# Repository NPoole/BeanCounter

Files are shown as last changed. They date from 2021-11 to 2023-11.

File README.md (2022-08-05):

# BeanCounter

[][cc-by-sa]

BeanCounter is an SMT parts counter that fits in your pocket. It’s battery powered and uses two IR photointerrupters to count parts about as fast as you can pull them through. It works with any opaque, 8-mm-wide carrier tape up to 2 mm in height, which covers most 0805-or-smaller LEDs and passives, as well as SOT23 transistors. It’s an affordable SMT tape counter without unnecessary bells and whistles.

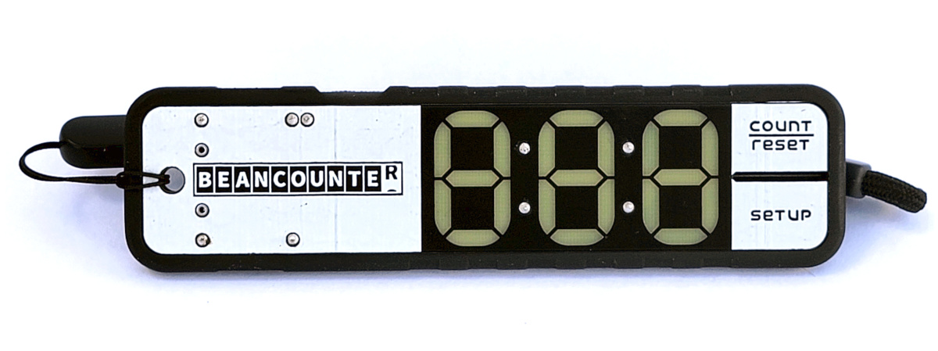
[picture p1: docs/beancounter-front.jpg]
BeanCounter on white background


## Available for Pre-Order Now on [Crowd Supply](https://www.crowdsupply.com/great-big-factory/beancounter)!

To use BeanCounter, simply turn it on and start pulling tape through. It will immediately begin counting your parts using one of two modes:

* Inventory Mode - Using just one sensor, BeanCounter polls at its fastest rate, allowing you to count long tapes and partial reels very quickly.
* Dispense Mode - With both sensors active, BeanCounter can detect the direction in which you are pulling tape, which allows it to count upward in one direction and downward in the other. This feature is useful in kitting contexts where you may be cutting fixed quantities off the end of a full reel.
Part pitch is configurable in either mode, so you can accurately count any part that physically fits through the counter.

Digging a little deeper, what BeanCounter actually does is count feed holes and divide by the part pitch. Because it cannot differentiate between parts and empty pockets, you will need to ensure that it begins counting after empty tape has been pulled through and stops counting before it reaches the tail. To help with this, we’ve added a "pause" button that you can use to freeze the count while pulling empty tape.

[cc-by-sa]: http://creativecommons.org/licenses/by-sa/4.0/
[cc-by-sa-shield]: https://img.shields.io/badge/License-CC%20BY--SA%204.0-lightgrey.svg

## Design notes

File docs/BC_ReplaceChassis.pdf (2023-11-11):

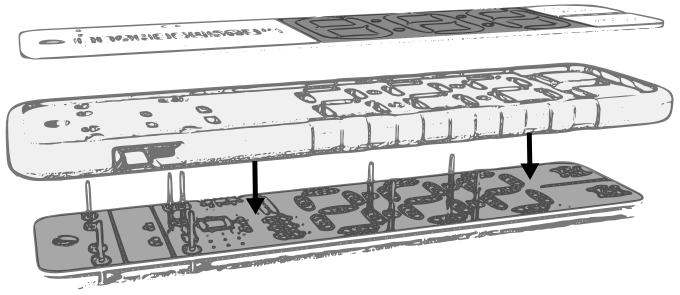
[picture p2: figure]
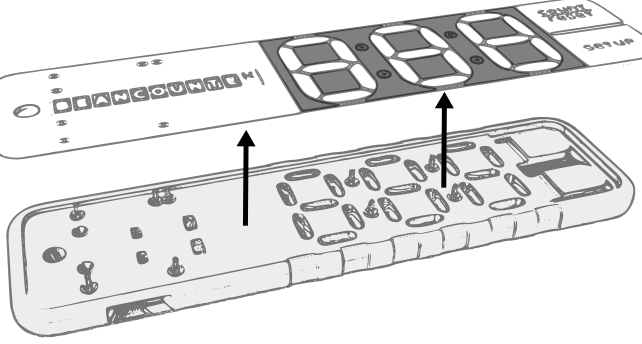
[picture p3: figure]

3609 Chapman Road
Wytheville, VA 24382 USA
support@greatbigfactory.com http://beancounter.wiki
OSHW UID US002097

CONTACT US

# How to Replace the Chassis

Step 1 - Desolder the Chassis Pins

Use a desoldering tool or copper wick to remove all solder from the 9 points indicated by the arrows below

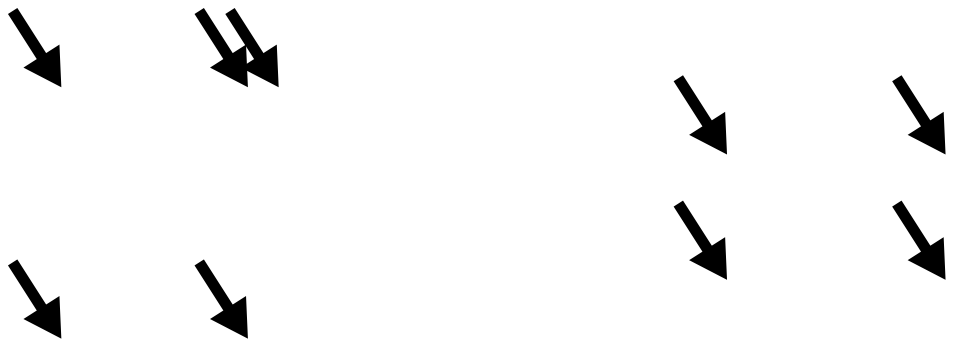
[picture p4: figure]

Step 2 - Remove the faceplate

Carefully pull the faceplate free from the rest of the assembly. If necessary, you can gently flex the chassis to reach a flat tool under the edge of the faceplate

Step 3 - Separate the backplate from the chassis
Step 4 - Re-Assemble the BeanCounter in the reverse order with your new chassis

The backplate should easily separate from the chassis. If necessary, you can press on the pins from the front to dislodge it.

Be sure that the face- and backplates are firmly seated into the chassis while soldering the 9 chassis pins. Using a small spring clamp can help, but it's sufficient to apply presure with your fingers.

.step | .stl

DOWNLOAD V11 CHASSIS MODELS

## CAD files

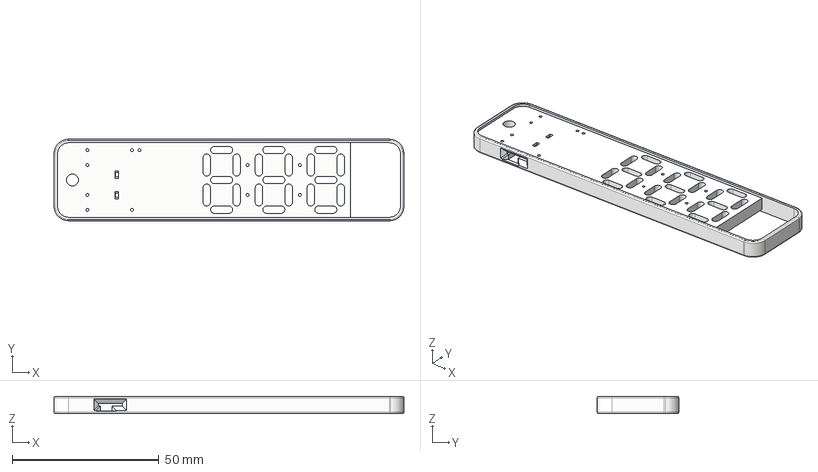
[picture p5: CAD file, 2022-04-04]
hardware/cad/BC_3DP_Simple_Resin v1.step
119.2 x 27.8 x 5.90 mm

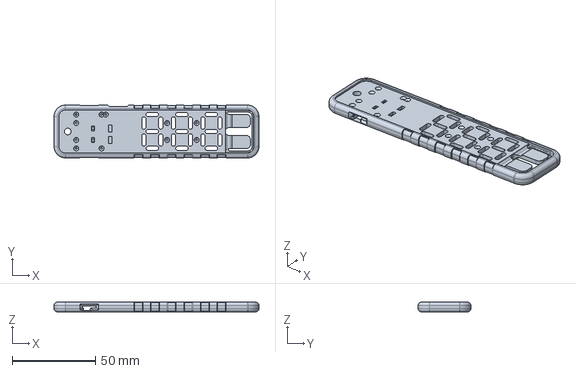
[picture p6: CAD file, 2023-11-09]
mechanical/BeanCounter_Rev11.step
123.2 x 31.8 x 5.90 mm

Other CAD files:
mechanical/BeanCounter_v10_Stock.step
mechanical/BeanCounter_Tall_Slot_Mod.stl
hardware/cad/BC_3DP_Simple_Resin v1.3mf
hardware/cad/BC_3DP_Simple_Resin v1.f3d
hardware/cad/BC_3DP_Simple_Resin v1.iges
mechanical/BeanCounter_Rev11.stl
mechanical/BeanCounter_v10_Stock.f3d
mechanical/BeanCounter_v10_Stock.stl

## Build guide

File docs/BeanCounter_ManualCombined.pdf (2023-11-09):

### SMT TAPE COUNTER V10 USER MANUAL

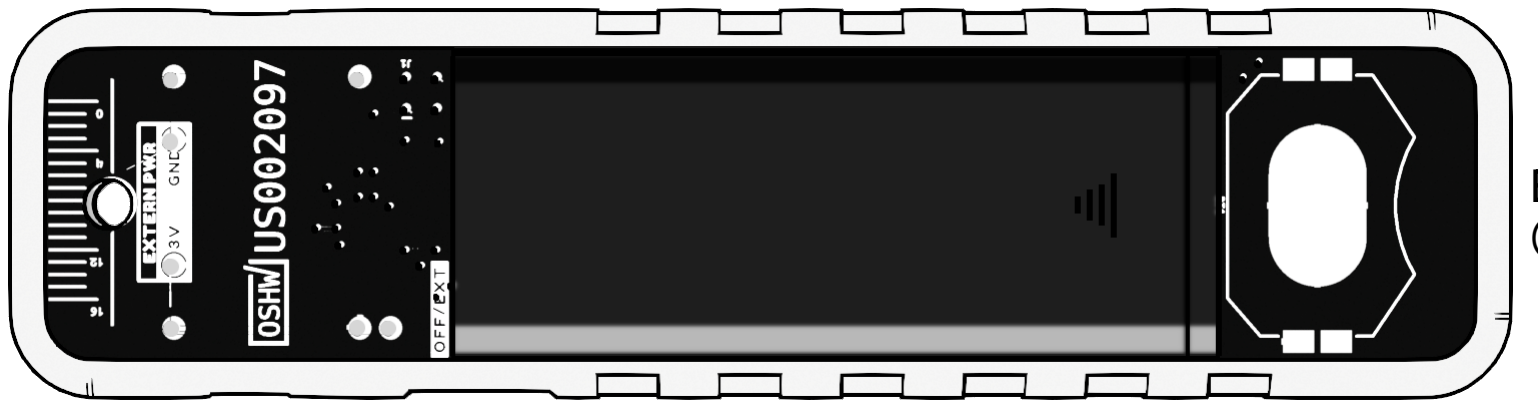
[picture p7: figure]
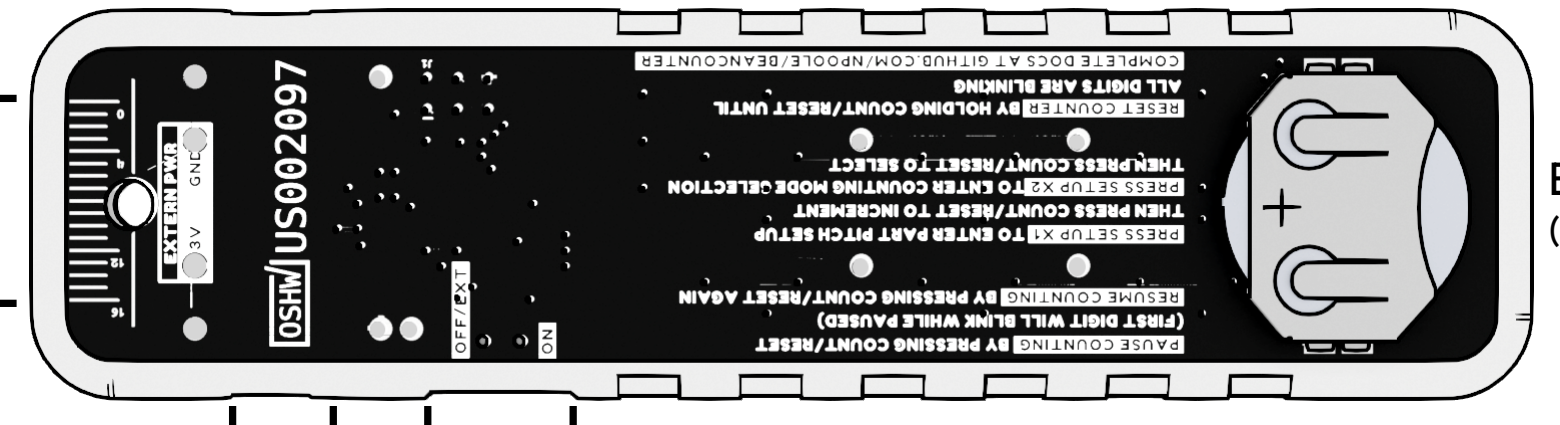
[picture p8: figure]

Display | Buttons

Tape
Slot

Power
Switch

Lanyard
Hole

BOTTOM VIEW
(BEANCOUNTER-10-BUBU)

-The batteries included with your BeanCounter are not rechargeable. These batteries could explode if you attempt to charge them. Do not attempt to charge disposable batteries.

Unit Size: 124x32x11mm (BEANCOUNTER-10) 124x32x24mm (BEANCOUNTER-10-BUBU) Unit Weight: ≈30g (BEANCOUNTER-10)
≈60g (BEANCOUNTER-10-BUBU) Batteries: "CR2032" Lithium Coin Cell or "LIR2032" Li-ion Rechargeable (BEANCOUNTER-10) 2 x "AAA" Alkaline or NiMH Rechargeable (BEANCOUNTER-10-BUBU)
Supported Tape Pitch in mm: 1, 2, 4, 8, 12, 16 Supported Tape Type: 8mm wide carrier tape, embossed plastic or paper type, <2mm part height.

-Before feeding carrier tape into the unit, cut off any empty portion of the tape. If this is impossible or undesirable, you must feed the empty portion through the unit before starting the count.
- In order to receive an accurate count, the part pitch must be set correctly. To do this, first press the SETUP button and observe that the display reads P followed by a number. This number is the pitch in millimeters. Press the COUNT/RESET button to increment this number. When the desired pitch is displayed, press SETUP twice to return to counting mode.

-If the display does not read 000 then it can be cleared by holding the COUNT/RESET button until the display begins to flash, and then releasing it.
-If the first digit of the display is flashing then the unit is paused. To begin counting, press the COUNT/RESET button. You can press the COUNT/RESET button at any time to turn off the sensors and pause counting without clearing the display.
-Carrier tape can be inserted into either end of the tape slot. However, the sprocket holes must be facing to the right (as viewed so that the BeanCounter logo is upright.)
-Pull or push the tape through the tape slot and observe that the parts count is increasing on the display. To ensure an accurate count, move the tape in a fluid motion and avoid jiggling or quickly switching the direction of motion.
-If the tape does not glide freely in the tape slot do not force it.
-In order to reset the count and clear the display, hold the COUNT/RESET button until the display begins to flash, and then release it.
-To ensure maximum battery life, turn the BeanCounter off when not in use.

BeanCounter has two counting modes: Inventory Mode and Dispense Mode. In Inventory Mode, the unit will use only one of its sensors to count as quickly as possible. This has the consequence that counts in both directions will be added together because the unit is unaware of the direction of count. This mode makes the BeanCounter capable of counting twice as fast, which is useful for counting long tape and partial reels. In Dispense Mode, the unit will use both of its sensors to count in both directions. This is handy for situations where you need to dispense a small number of parts such as when kitting or packing.

To switch modes, press the SETUP button twice and observe that the display reads either d15 for Dispense Mode or1nu for Inventory Mode. Press the COUNT/RESET button to toggle modes. When the desired mode is displayed, press the SETUP button to return to counting mode.

3609 Chapman Road
Wytheville, VA 24382 USA
support@greatbigfactory.com http://beancounter.wiki
OSHW UID US002097

-Do not place your BeanCounter on or allow it to rest on an electrically conductive surface.

Read and understand this manual and all safety instructions before operating this equipment.

The BeanCounter product is provided "AS IS." Great Big Factory makes no warranty, representation, or guarantee as to the fitness of this device for any specific purpose, nor does Great Big Factory assume any liability whatsoever arising from the function or malfunction of the BeanCounter device (to the extent permissible by law.) Great Big Factory assumes no obligation to replace or repair a BeanCounter device for any reason.

Due to physical limitations of the sensor, BeanCounter is not compatible with transparent carrier tapes.

-Do not place anything into the tape slot other than embossed plastic or paper carrier tape.

-Do not submerge or otherwise expose your BeanCounter to water.

BOTTOM VIEW
(BEANCOUNTER-10)

TOP VIEW
(ALL MODELS)

Pitch
Ruler
SAFETY INFORMATION | GENERAL OPERATION Preparation

## Counting

## Selecting a Counting Mode

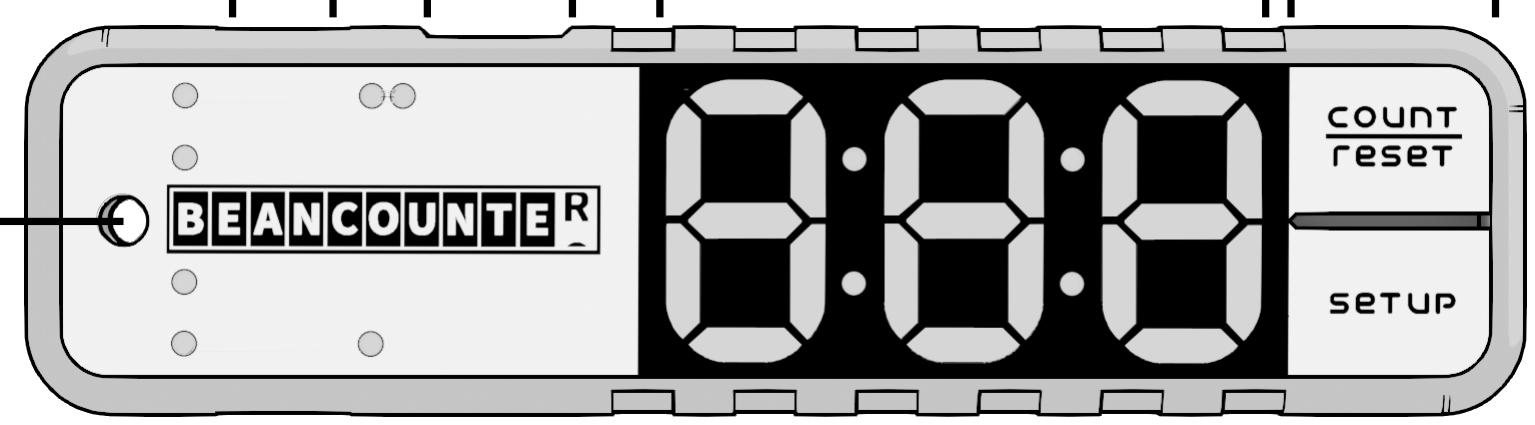
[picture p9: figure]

## Find tips, troubleshooting, and detailed operating instructions at: http://beancounter.wiki

# SPECIFICATIONS

WARRANTY DISCLAIMER | CONTACT US

# EQUIPMENT DIAGRAM

Manufactured in Partnership With | Made Possible By
&

!

### SMT BANDZÄHLER

V10 BEDIENUNGSANLEITUNG

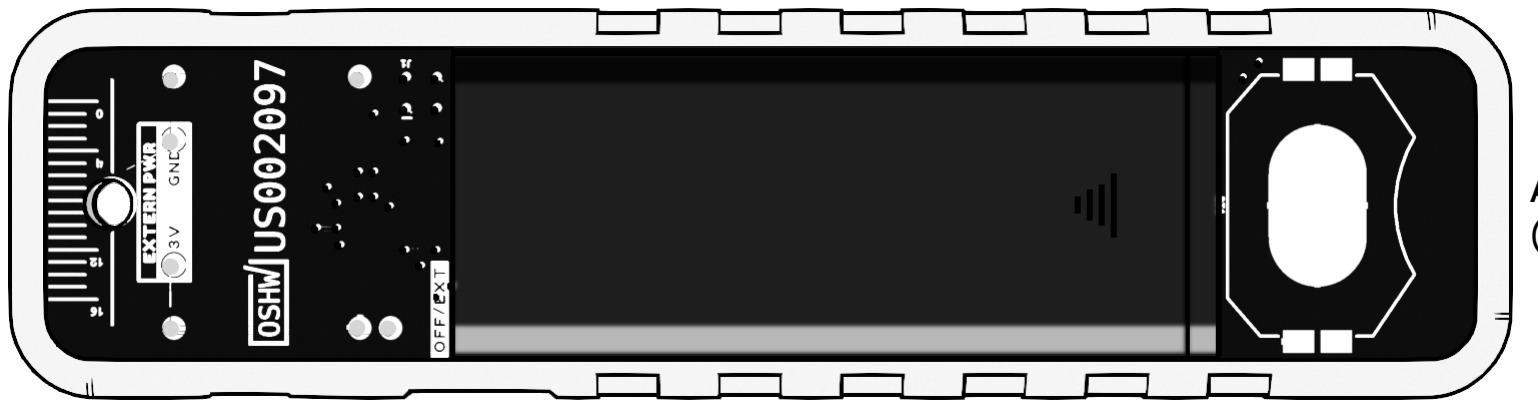
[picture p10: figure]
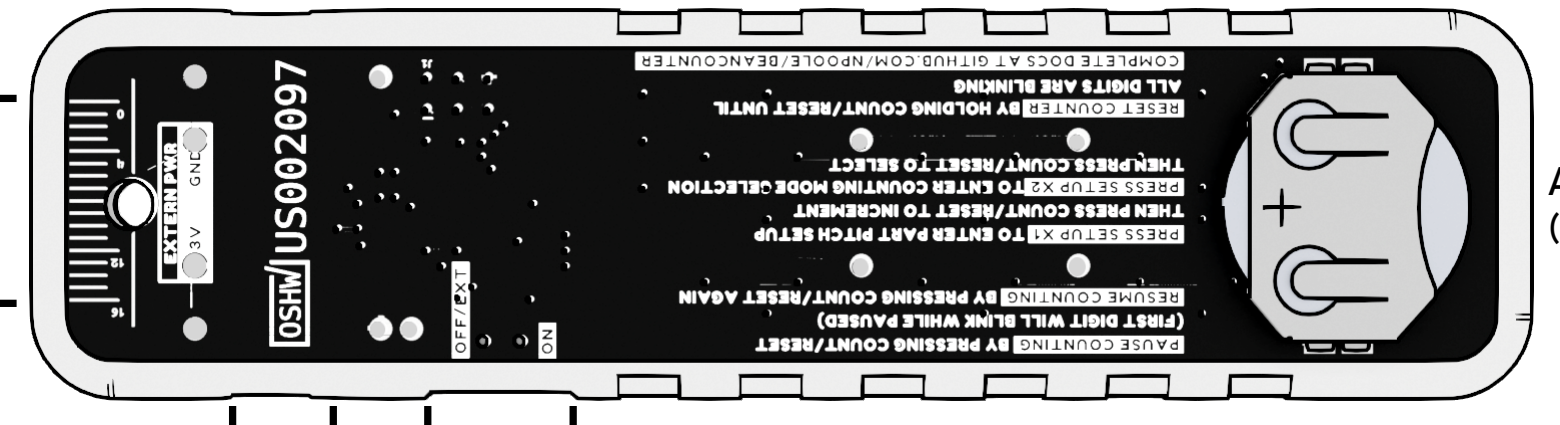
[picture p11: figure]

Anzeige | Tasten Gurtschlitz | Ein-/Ausschalter

Lanyard-Loch

ANSICHT VON UNTEN
(BEANCOUNTER-10-BUBU)

-Die Ihrem BeanCounter beiliegenden Batterien
sind nicht wiederaufladbar. Beim Versuch, sie aufzuladen, können diese Batterien explodieren. Bitte versuchen Sie nicht, Einwegbatterien aufzuladen.

Abmessungen: 124x32x11mm (BEANCOUNTER-10) 124x32x24mm (BEANCOUNTER-10-BUBU) Gewicht: ≈30g (BEANCOUNTER-10)
≈60g (BEANCOUNTER-10-BUBU) Batterien: "CR2032" Lithium-Knopfzelle oder "LIR2032" Li-Ionen-Akku (BEANCOUNTER-10)
2 x "AAA" Alkaline oder NiMH wiederaufladbar (BEANCOUNTER-10-BUBU)
Verwendbare Gurtabstand in mm: 1, 2, 4, 8, 12, 16 Verwendbare Gurttypen: 8mm gurtbreiten ,
Gurten aus Karton oder Kunststoff, <2mm Profilhöhe.

-Bitte schneiden Sie vor dem Einführen des Gurte in das Gerät den leeren Teil des Gurte
ab. Falls dies nicht möglich oder unerwünscht ist, führen Sie den leeren Teil durch das Gerät, bevor Sie mit der Zählung beginnen.
- Um eine exakte Zählung zu erhalten, muss der Teilungsabstand korrekt eingestellt sein. Dazu drücken Sie zunächst die SETUP-Taste und beobachten, dass auf dem Display P gefolgt von einer Zahl erscheint. Bei dieser Zahl handelt es sich um die Teilung in Millimetern. Betätigen Sie die COUNT/RESET-Taste, um diese Zahl zu erhöhen. Sobald die gewünschte Tonhöhe angezeigt wird, drücken Sie zweimal SETUP, um in den Zählmodus zurückzukehren.

-Falls die Anzeige nicht 000 anzeigt, kann sie gelöscht werden, indem Sie die Taste COUNT/RESET gedrückt halten, bis die Anzeige zu blinken beginnt, und sie dann loslassen.
-Blinkt die erste Ziffer auf der Anzeige, ist das Gerät pausiert. Um den Zählvorgang zu starten, drücken Sie die COUNT/RESET-Taste. Um die Sensoren auszuschalten und die Zählung zu unterbrechen, ohne die Anzeige zu löschen, können Sie jederzeit die COUNT/RESET-Taste drücken. -Das Trägerband lässt sich in beide Enden des Gurtschlitzes einführen. Jedoch müssen die Stachelradlöcher nach rechts gerichtet sein (so gesehen, dass das BeanCounter-Logo
aufrecht steht).
-Das Gurt durch den Gurtschlitz ziehen oder schieben und darauf achten, dass die Anzahl der Teile auf dem Display Anzeige steigt. Bewegen Sie das Gurt in einer fließenden Bewegung und vermeiden Sie ein Wackeln oder einen schnellen Wechsel der Bewegungsrichtung, um eine genaue Zählung zu gewährleisten.
-Gleitet das Gurt nicht ungehindert in den Gurtschlitz, sollten Sie es nicht mit Gewalt bewegen. -Zum Zurücksetzen der Zählung und Löschen der Anzeige halten Sie die COUNT/RESET-Taste gedrückt, bis die Anzeige zu blinken beginnt, und lassen Sie sie dann los.
-Um die Lebensdauer der Batterie zu verlängern, schalten Sie den BeanCounter aus, wenn er nicht benutzt wird.

BeanCounter verfügt über zwei Zählmodi: Inventar-Modus und Dispense-Modus. Im Inventar-Modus wird das Gerät nur einen seiner Sensoren verwenden, um so schnell wie möglich zu zählen. Dadurch werden die Zählungen in beide Richtungen addiert, da dem Gerät die Zählrichtung nicht bekannt ist. Der BeanCounter ist in diesem Modus in der Lage, doppelt so schnell zu zählen, was beim Zählen von langen Gurten und Rolle nützlich ist. Im Dispense-Modus nutzt das Gerät
beide Sensoren, um in beide Richtungen zu zählen. Diese Funktion ist praktisch für Situationen, in denen Sie eine kleine Anzahl von Teilen ausgeben müssen, wie z.B. beim Kitting oder Verpacken.

Um die Modi zu wechseln, betätigen Sie zweimal die SETUP-Taste und achten Sie darauf, dass auf der Anzeige entweder d15 für den Dispense-Modus oder1nu für den Inventar-Modus erscheint. Zum Umschalten der Modi drücken Sie die Taste COUNT/RESET. Sobald der gewünschte Modus angezeigt wird, drücken Sie die SETUP-Taste, um zum Zählmodus zurückzukehren.

3609 Chapman Road
Wytheville, VA 24382 USA
support@greatbigfactory.com http://beancounter.wiki
OSHW UID US002097

-Den BeanCounter nicht auf eine elektrisch leitfähige Oberfläche stellen oder liegen lassen.

Bitte lesen und befolgen Sie dieses Bedienungsanleitung und alle Sicherheitshinweise, bevor Sie das Gerät in Betrieb nehmen.

Dieses Produkt wird ohne Mängelgewähr bereitgestellt.
Great Big Factory übernimmt keine Garantie, Zusicherung oder Gewährleistung für die Eignung dieses Geräts für einen bestimmten Zweck, noch übernimmt Great Big Factory irgendeine Haftung, die sich aus der Funktion oder Fehlfunktion des BeanCounter-Geräts ergibt (soweit gesetzlich zulässig). Great Big Factory ist nicht verpflichtet, ein BeanCounter Gerät aus irgendeinem Grund zu ersetzen oder zu reparieren.

Infolge der physikalischen Limitierungen des Sensors ist der BeanCounter nicht mit transparenten Gurte kompatibel.

-Keine anderen Gegenstände als Gurte in den Gurtschlitz stecken.

-Bitte niemals den BeanCounter unter Wasser tauchen oder anderweitig mit Wasser in Berührung bringen.

ANSICHT VON UNTEN
(BEANCOUNTER-10)

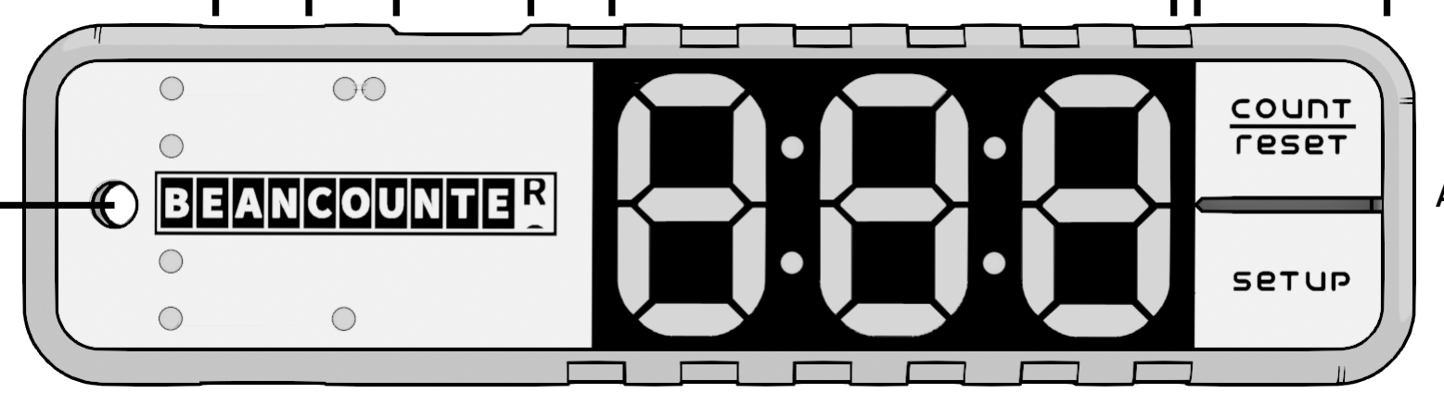
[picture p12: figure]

ANSICHT VON OBEN

Lineal

SICHERHEITSHINWEISE | ALLGEMEINE BEDIENUNG Vorbereitung

## Zählen

## Zählmodus auswählen

Hinweise, Problemlösungen und detaillierte Bedienungsanleitungen finden Sie unter:

## http://beancounter.wiki

# TECHNISCHE ANGABEN

HAFTUNGSAUSSCHLUSS | KONTAKT

# GERÄTEÜBERSICHT

Hergestellt in Partnerschaft mit | Ermöglicht durch
&

!

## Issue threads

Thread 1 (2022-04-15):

Bill of materials

foorschtbar, 2022-04-15:
Very cool gadget you have developed. I liked it since i saw it on twitter.

Will you upload a BOM so that everybody can build the BeanCounter yourself - or did I just overlook that?

e-tinkers, 2022-04-18:
Well, for those who know electronics and embedded programming, one could create a device like this and write his own code even without seeing the schematic.

For those who can't even generate the BOM (or who is capable but unwilling to invest time on it) when giving the component footprints, PCB layout and schematic, maybe one should just buy one from the @Npoole and support his [CrownSupply](https://www.crowdsupply.com/great-big-factory/beancounter) project.

foorschtbar, 2022-04-21:
I have not seen that the Eagle files are there. Now everything is clear.

Closed 2022-04-21.

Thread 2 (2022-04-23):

Design enhancements

j3qq4hch, 2022-04-23:
Greetings! I really like your idea and the implementation in a form if mostly PCBs.
I hope your crowdsupply campaign will be succesfull.
However I see at least several improvements to this project that may be very useful for high scale manufacturability, BOM cost and components lead time reduction. As well as for higher device reliability. Please let me know if you are interested. If not - just delete this issue.
Best regards.

NPoole, 2022-04-29:
I think we're locked in for the campaign hardware, but I'm happy to hear any feedback you have for future revisions or "Pro" model offerings.

j3qq4hch, 2022-04-29:
Well, I will just leave a small list of enhancements here
- Switch to a cheaper and more available MCU like something from STM32G0 series
- Get rid of the 3d printed part and replace it with either another PCB or laser cut plastic part.
- The way everything holds together using soldered pins is a bit untidy...  It is always better if no circuitry is exposed. Also, its good to have a device that can actually be disassembled with a screwdriver
- It seems like something has to be done with the indicator. I think its readability can be improved a bit.
- I am not sure but it seems that mechanical buttons may be replaced with sensor ones. It may reduce the BOM cost a little bit and also ease the overall construction.

NPoole, 2022-05-16:
Thanks for your time! I'm going to leave this issue open for the time being while I collect feedback and compile it.

je2442, 2023-08-31:
I would add a few things to the list:

- It would be really nice if it could be enhanced to handle slightly taller and possibly wider components (1206 and SOD-123, for a couple of examples).
- I find that the count is sometimes off by 2 or 4...not sure why.  That's not a huge issue for me, but I wonder if that could be improved.  Maybe it depends on where the tape is cut exactly in relation to the holes.
- I also think the LED display readability should be improved a bit.  Some of our office lighting makes it unreadable.
- Future enhancement to work with additional tape widths would be great.
- I might try to retrofit mine with a rechargeable battery.  That would be a good option for future consideration.

It is pretty nice for a budget-friendly counter, though!

Geo-7777, 2025-03-28:
For our application we would need a 4th digit our counts are usually close to 3000 to 4000 pcs otherwise your unit works really well for our needs, hope you consider this in your next revision

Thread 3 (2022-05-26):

Suggestion: wirless capability

matmair, 2022-05-26:
Hi there @NPoole !
Cool project. If you end up spinning up a rev 2 it would be cool to have some wireless function included if it fits in your overall plan for the product. This would be helpful to get the current count into an ERP/PLM.
Several interfaces would be beneficial:
- *Wifi* would require some primitive API that can be queried but could be very versetail
- *Bluetooth* provides a profile for scales that could be used and you could connect multiple
- *NFC* could just return the current number - the device would have to be tapped for that

The subject came up in the form of the question of how the BeanCounter could be integrated in the community for [InvenTree](https://github.com/inventree/InvenTree) - an open-source PLM.

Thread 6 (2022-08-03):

Polygon errors on board maker website

alex-x-taylor, 2022-08-03:
I attempted to upload the .brd files to get some boards made (oshpark) and got an error code. After reaching out to support and submitting a file to them they say that there are some polygons with mismatch ends. An example they gave was instead of a corner coming to a nice 90 degree point, it overlaps and turns into a small bow tie. I'm planning on combing through the board designs and looking for any wayward polygons.

Thanks for your hard work!

NPoole, 2022-08-05:
Yeah, I'm aware of these errors because both Eagle and the CAM script that I use to generate the gerber files complain about them. They're the result of images that were generated from SVGs using another tool that I created called "Vulture" which still has bugs in it. If you manage to manually correct the polygons, please submit a pull request and I'll pull the corrected polygons so future DIYers don't have to deal with them. Thanks!

Closed 2022-08-05.

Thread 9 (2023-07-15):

Power consumption improvements

kontakt, 2023-07-15:
Changing the device clock to 1MHz (Internal) drops current draw from 19mA to 8mA with no observed degrading of count performance.
I hope to implement additional power saving features.

kontakt, 2023-07-15:
Brought it down to 4.5mA with ADC powerdown.

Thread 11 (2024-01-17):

Trying to get BEancounter working for first time since receiving, but doesn't seem to count.

thisisformuchfun, 2024-01-17:
Hey there, big fan, but unfortunately my beancounter doesn't appear to work - I legit had no reels or cut tape for a long time, lol, #US002097. It seems to turn on and set mode properly with all the youtube videos and documentation I've found, but doesn't count.

I did notice it was a bit bent when received, not sure if there was something with that - I wanted to take it apart and look at the soldering pads around that sensor, but I can't disassemble it, seems pretty tight lol.

Any advice or suggestions to look at?

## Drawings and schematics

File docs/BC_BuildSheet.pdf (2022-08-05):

## PCB Assembly Reference

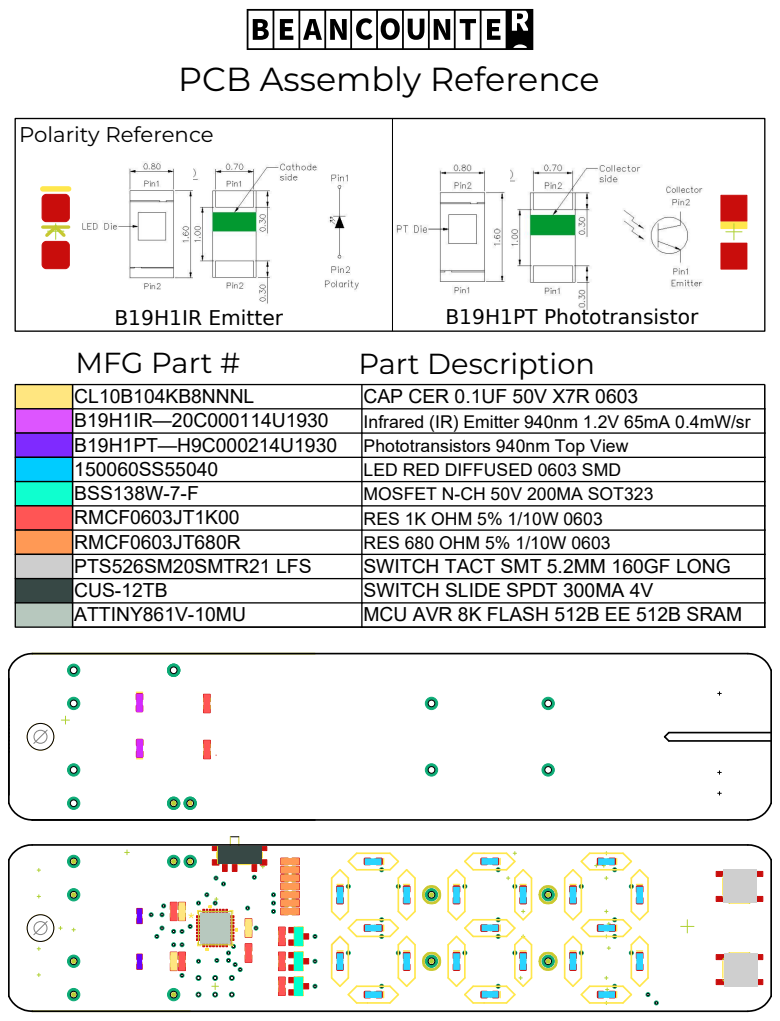
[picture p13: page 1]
MFG Part #; Part Description; Polarity Reference; B19H1IR Emitter; B19H1PT Phototransistor

CL10B104KB8NNNL | CAP CER 0.1UF 50V X7R 0603
B19H1IR—20C000114U1930 | Infrared (IR) Emitter 940nm 1.2V 65mA 0.4mW/sr
B19H1PT—H9C000214U1930 | Phototransistors 940nm Top View
150060SS55040 | LED RED DIFFUSED 0603 SMD
BSS138W-7-F | MOSFET N-CH 50V 200MA SOT323
RMCF0603JT1K00 | RES 1K OHM 5% 1/10W 0603
RMCF0603JT680R | RES 680 OHM 5% 1/10W 0603
PTS526SM20SMTR21 LFS | SWITCH TACT SMT 5.2MM 160GF LONG
CUS-12TB | SWITCH SLIDE SPDT 300MA 4V
ATTINY861V-10MU | MCU AVR 8K FLASH 512B EE 512B SRAM

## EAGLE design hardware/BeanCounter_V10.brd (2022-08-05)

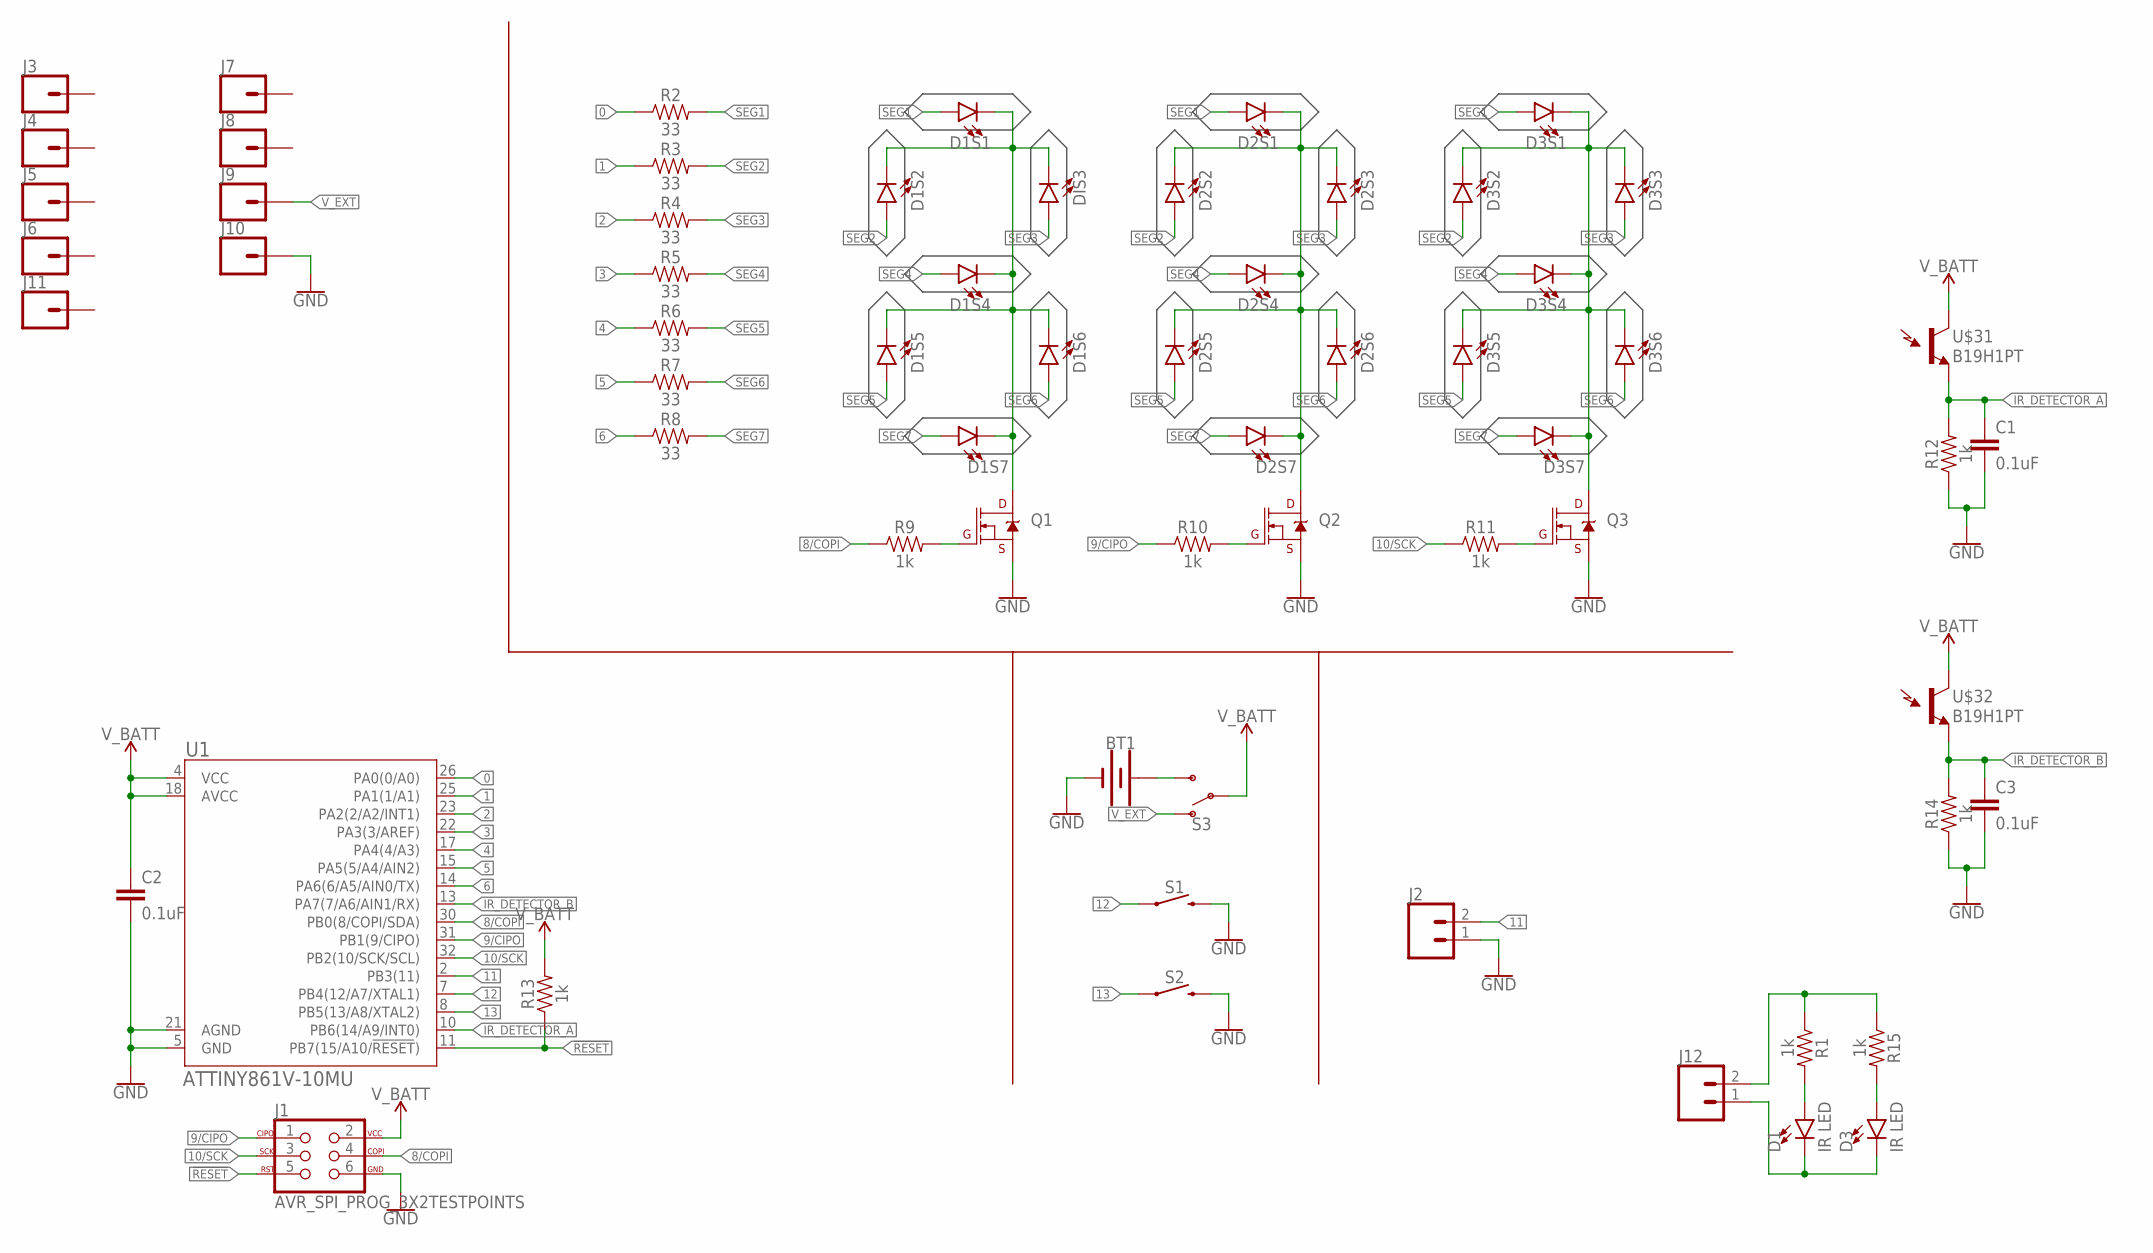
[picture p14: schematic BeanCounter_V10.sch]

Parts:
BT1: BATTERY-20MM_SMD_4LEGS_OVERPASTE_INNER; BATTCON_20MM_4LEGS_OVERPASTE_INNER
C1, C2, C3: 0.1uF; 0603
D1, D3: IR LED; LED-0603
D1S1, D1S2, D1S4, D1S5, D1S6, D1S7, D2S1, D2S2, D2S3, D2S4, D2S5, D2S6, D2S7, D3S1, D3S2, D3S3, D3S4, D3S5, D3S6, D3S7: LED0603; LED-0603
DIS3: LED0603; LED-0603
J1: AVR_SPI_PROG_3X2TESTPOINTS; 2X3_TEST_POINTS
J2, J12: CONN_02; 1X02
J3, J4, J5, J6, J7, J8, J9, J10, J11: CONN_01; 1X01
Q1, Q2, Q3: 220mA/50V/3.5Ω; SOT23-3
R1, R9, R10, R11, R12, R13, R14, R15: 1k; 0603
R2, R3, R4, R5, R6, R7, R8: 33; 0603
S1, S2: MOMENTARY-SWITCH-SPST-SMD-5.2MM-TALL; TACTILE_SWITCH_SMD_5.2MM
S3: SWITCH-SPDT-SMD-RIGHT-ANGLE; SWITCH_SPST_SMD_A
U1: ATTINY861V-10MU; 32M1-A_ATM
U$31, U$32: B19H1PT; HARVATEK_DETECTOR

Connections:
0: R2.1, U1.26 (PA0(0/A0))
1: R3.1, U1.25 (PA1(1/A1))
2: R4.1, U1.23 (PA2(2/A2/INT1))
3: R5.1, U1.22 (PA3(3/AREF))
4: R6.1, U1.17 (PA4(4/A3))
5: R7.1, U1.15 (PA5(5/A4/AIN2))
6: R8.1, U1.14 (PA6(6/A5/AIN0/TX))
8/COPI: J1.4, R9.1, U1.30 (PB0(8/COPI/SDA))
9/CIPO: J1.1, R10.1, U1.31 (PB1(9/CIPO))
10/SCK: J1.3, R11.1, U1.32 (PB2(10/SCK/SCL))
11: J2.2, U1.2 (PB3(11))
12: S1.1, U1.7 (PB4(12/A7/XTAL1))
13: S2.1, U1.8 (PB5(13/A8/XTAL2))
!RESET: J1.5, R13.1, U1.11 (PB7(15/A10/!RESET!))
GND: BT1.2 (-), C1.2, C2.2, C3.2, J1.6, J2.1, J10.1, Q1.2 (S), Q2.2 (S), Q3.2 (S), R12.1, R14.1, S1.3 (2), S2.3 (2), U1.5 (GND), U1.21 (AGND)
IR_DETECTOR_A: C1.1, R12.2, U1.10 (PB6(14/A9/INT0)), U$31.P$2 (E1)
IR_DETECTOR_B: C3.1, R14.2, U1.13 (PA7(7/A6/AIN1/RX)), U$32.P$2 (E1)
unnamed: BT1.1 (+), S3.3 (S)
unnamed: D1S1.C, D1S2.C, D1S4.C, D1S5.C, D1S6.C, D1S7.C, DIS3.C, Q1.3 (D)
unnamed: Q2.1 (G), R10.2
unnamed: Q1.1 (G), R9.2
unnamed: D2S1.C, D2S2.C, D2S3.C, D2S4.C, D2S5.C, D2S6.C, D2S7.C, Q2.3 (D)
unnamed: Q3.1 (G), R11.2
unnamed: D3S1.C, D3S2.C, D3S3.C, D3S4.C, D3S5.C, D3S6.C, D3S7.C, Q3.3 (D)
unnamed: D3.A, R15.2
unnamed: D1.A, R1.2
unnamed: J12.2, R1.1, R15.1
unnamed: D1.C, D3.C, J12.1
SEG1: D1S1.A, D2S1.A, D3S1.A, R2.2
SEG2: D1S2.A, D2S2.A, D3S2.A, R3.2
SEG3: D2S3.A, D3S3.A, DIS3.A, R4.2
SEG4: D1S4.A, D2S4.A, D3S4.A, R5.2
SEG5: D1S5.A, D2S5.A, D3S5.A, R6.2
SEG6: D1S6.A, D2S6.A, D3S6.A, R7.2
SEG7: D1S7.A, D2S7.A, D3S7.A, R8.2
V_BATT: C2.1, J1.2, R13.2, S3.2, U1.4 (VCC), U1.18 (AVCC), U$31.P$1 (C1), U$32.P$1 (C1)
V_EXT: J9.1, S3.1 (O)

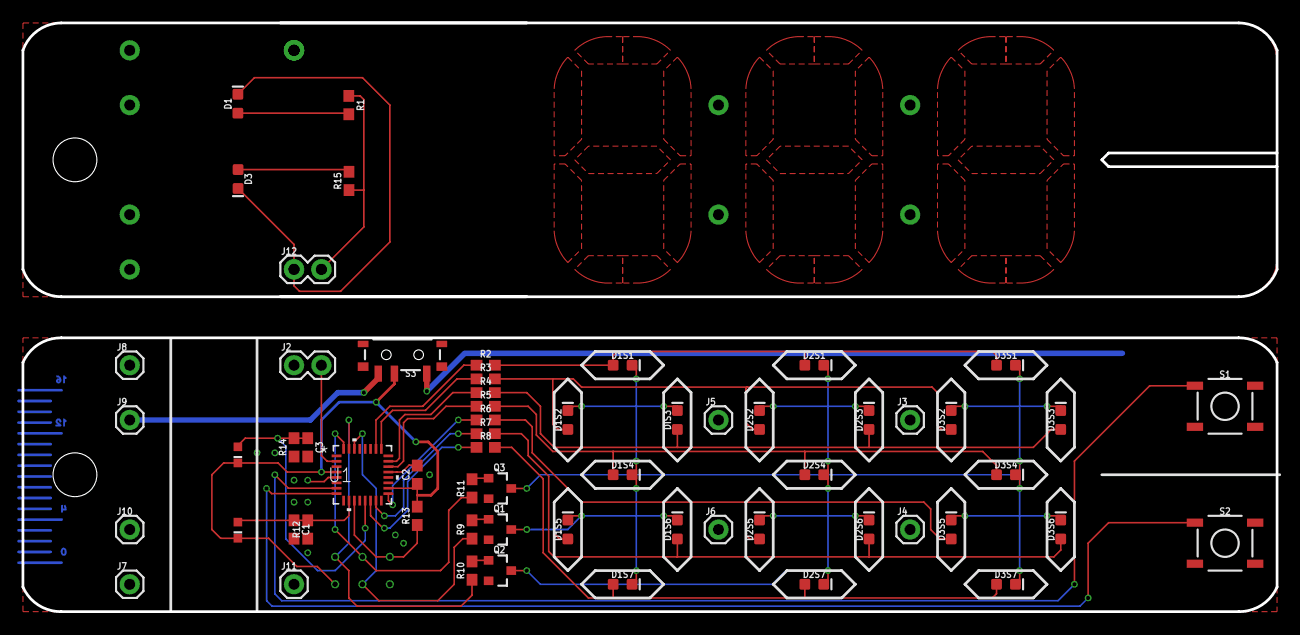
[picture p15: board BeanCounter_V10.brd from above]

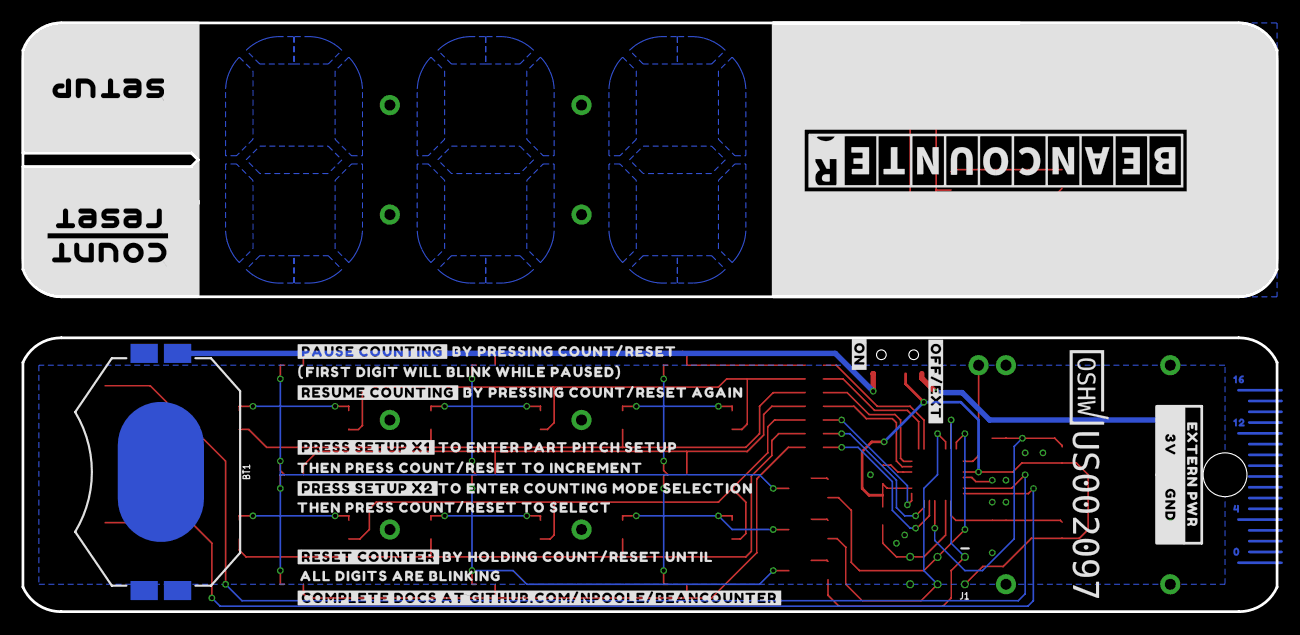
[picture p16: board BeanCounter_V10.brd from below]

Board: 2 copper layers, 116.3 x 25.4 mm, 93 parts (32 on the bottom side), 37 nets.

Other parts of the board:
U$1: OSHWBC#SVG0
U$2: EXTERN_PWR0
U$3: #PAUSE_COUNTING#0
U$4: #PRESS_SETUP_X1#0
U$5: 00
U$6: #_3V#0
U$7: #_GND#0
U$8: THEN_PRESS_COUNT#RESET_TO_INCREMENT0
U$9: BY_PRESSING_COUNT#RESET0
U$10: FIRST_DIGIT_WILL_BLINK_WHILE_PAUSED#_0
U$11: #_0
U$12: #RESUME_COUNTING#0
U$13: BY_PRESSING_COUNT#RESET_AGAIN0
U$14: TO_ENTER_PART_PITCH_SETUP0
U$15: #PRESS_SETUP_X2#0
U$16: TO_ENTER_COUNTING_MODE_SELECTION0
U$17: THEN_PRESS_COUNT#RESET_TO_SELECT0
U$18: #RESET_COUNTER#0
U$19: BY_HOLDING_COUNT#RESET_UNTIL0
U$20: 40
U$21: 120
U$22: 160
U$23: #ON#0
U$24: #OFF#EXT#0
U$25: ALL_DIGITS_ARE_BLINKING0
U$26: #COMPLETE_DOCS_AT_GITHUB#COM#NPOOLE#BEANCOUNTER#0
U$27: #COUNT#0
U$28: #RESET#0
U$29: #SETUP#0
U$30: LOGO#SVG0

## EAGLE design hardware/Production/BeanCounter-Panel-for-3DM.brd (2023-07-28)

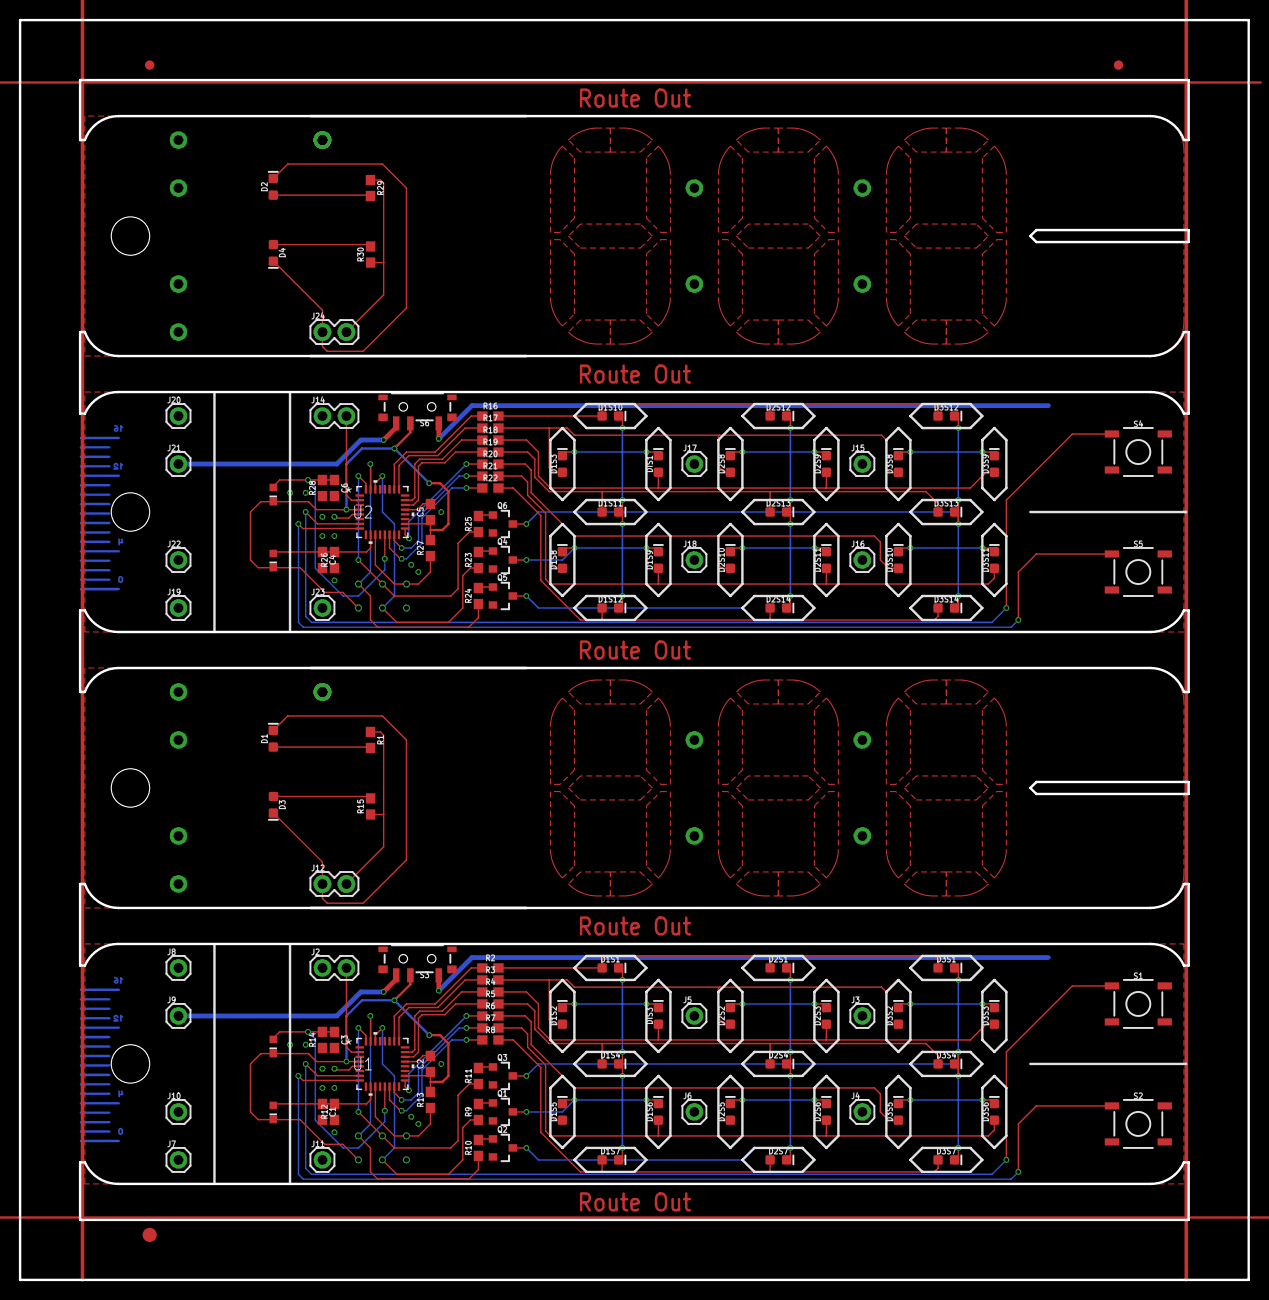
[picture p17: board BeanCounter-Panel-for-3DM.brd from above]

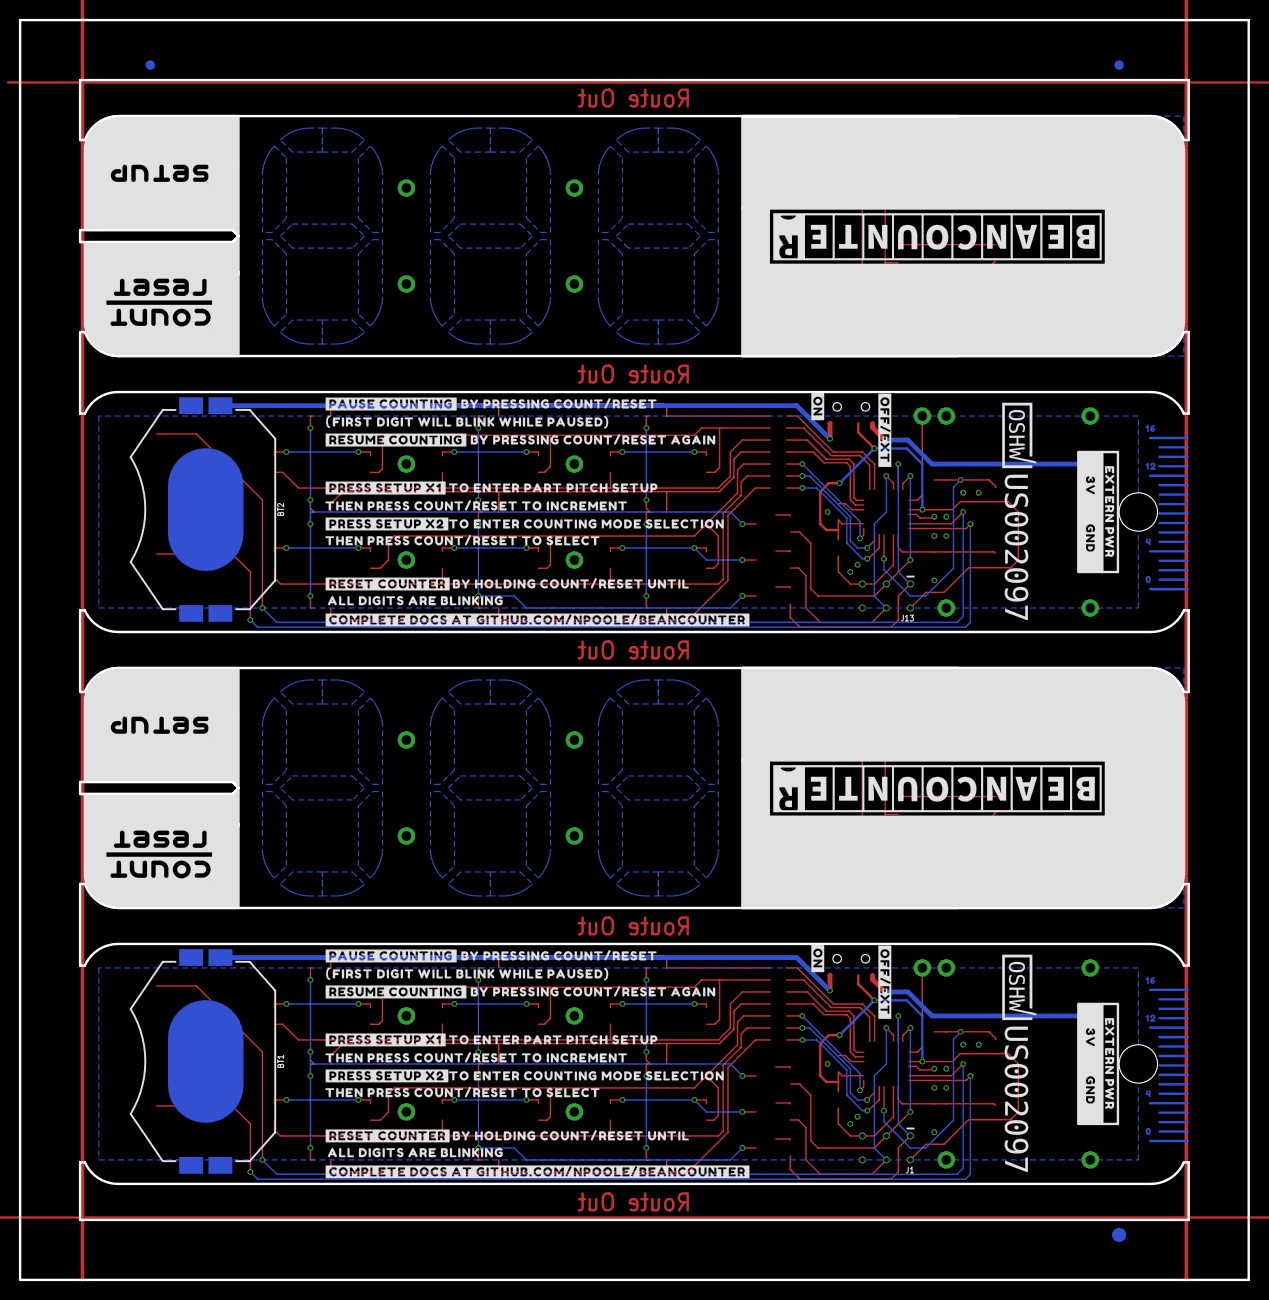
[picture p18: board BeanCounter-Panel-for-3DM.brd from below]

Board: 2 copper layers, 130.0 x 133.3 mm, 192 parts (67 on the bottom side), 74 nets.

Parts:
BT1, BT2: BATTCON_20MM_4LEGS_OVERPASTE_INNER
C1, C2, C3, C4, C5, C6: 0.1uF; 0603
D1, D2, D3, D4: IR LED; LED-0603
D1S1, D1S2, D1S3, D1S4, D1S5, D1S6, D1S7, D1S8, D1S9, D1S10, D1S11, D1S12, D2S1, D2S2, D2S3, D2S4, D2S5, D2S6, D2S7, D2S8, D2S9, D2S10, D2S11, D2S12, D2S13, D2S14, D3S1, D3S2, D3S3, D3S4, D3S5, D3S6, D3S7, D3S8, D3S9, D3S10, D3S11, D3S12, D3S13, D3S14: LED-0603
DIS1, DIS3: LED-0603
E$1, E$2, E$3, E$4: FIDUCIAL-1X2
E$5, E$6: FIDUCIAL-1.5X3
J1, J13: AVR_SPI_PROG_3X2TESTPOINTS; 2X3_TEST_POINTS
J2, J12, J14, J24: 1X02
J3, J4, J5, J6, J7, J8, J9, J10, J11, J15, J16, J17, J18, J19, J20, J21, J22, J23: 1X01
Q1, Q2, Q3, Q4, Q5, Q6: 220mA/50V/3.5Ω; SOT23-3
R1, R9, R10, R11, R12, R13, R14, R15, R23, R24, R25, R26, R27, R28, R29, R30: 1k; 0603
R2, R3, R4, R5, R6, R7, R8, R16, R17, R18, R19, R20, R21, R22: 33; 0603
S1, S2, S4, S5: MOMENTARY-SWITCH-SPST-SMD-5.2MM-TALL; TACTILE_SWITCH_SMD_5.2MM
S3, S6: SWITCH_SPST_SMD_A
U1, U2: ATTINY861V-10MU; 32M1-A_ATM
U$1, U$41: OSHWBC#SVG0
U$2, U$42: EXTERN_PWR0
U$3, U$43: #PAUSE_COUNTING#0
U$4, U$49: #PRESS_SETUP_X1#0
U$5, U$35: 00
U$6, U$33: #_3V#0
U$7, U$34: #_GND#0
U$8, U$51: THEN_PRESS_COUNT#RESET_TO_INCREMENT0
U$9, U$44: BY_PRESSING_COUNT#RESET0
U$10, U$45: FIRST_DIGIT_WILL_BLINK_WHILE_PAUSED#_0
U$11, U$46: #_0
U$12, U$47: #RESUME_COUNTING#0
U$13, U$48: BY_PRESSING_COUNT#RESET_AGAIN0
U$14, U$50: TO_ENTER_PART_PITCH_SETUP0
U$15, U$52: #PRESS_SETUP_X2#0
U$16, U$53: TO_ENTER_COUNTING_MODE_SELECTION0
U$17, U$54: THEN_PRESS_COUNT#RESET_TO_SELECT0
U$18, U$55: #RESET_COUNTER#0
U$19, U$56: BY_HOLDING_COUNT#RESET_UNTIL0
U$20, U$36: 40
U$21, U$37: 120
U$22, U$38: 160
U$23, U$39: #ON#0
U$24, U$40: #OFF#EXT#0
U$25, U$57: ALL_DIGITS_ARE_BLINKING0
U$26, U$58: #COMPLETE_DOCS_AT_GITHUB#COM#NPOOLE#BEANCOUNTER#0
U$27, U$59: #COUNT#0
U$28, U$60: #RESET#0
U$29, U$61: #SETUP#0
U$30, U$62: LOGO#SVG0
U$31, U$32, U$63, U$64: B19H1PT; HARVATEK_DETECTOR

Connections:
0: R2.1, U1.26
1: R3.1, U1.25
2: R4.1, U1.23
3: R5.1, U1.22
4: R6.1, U1.17
5: R7.1, U1.15
6: R8.1, U1.14
7: R16.1, U2.26
8: R17.1, U2.25
8/COPI: J1.4, R9.1, U1.30
8/COPI1: J13.4, R23.1, U2.30
9: R18.1, U2.23
9/CIPO: J1.1, R10.1, U1.31
9/CIPO1: J13.1, R24.1, U2.31
10: R19.1, U2.22
10/SCK: J1.3, R11.1, U1.32
10/SCK1: J13.3, R25.1, U2.32
11: J2.2, U1.2
12: S1.1, U1.7
13: S2.1, U1.8
14: R20.1, U2.17
15: R21.1, U2.15
16: R22.1, U2.14
17: J14.2, U2.2
18: S4.1, U2.7
19: S5.1, U2.8
!RESET: J1.5, R13.1, U1.11
!RESET1: J13.5, R27.1, U2.11
GND: BT1.2, C1.2, C2.2, C3.2, J1.6, J2.1, J10.1, Q1.2, Q2.2, Q3.2, R12.1, R14.1, S1.3, S2.3, U1.5, U1.21
GND1: BT2.2, C4.2, C5.2, C6.2, J13.6, J14.1, J22.1, Q4.2, Q5.2, Q6.2, R26.1, R28.1, S4.3, S5.3, U2.5, U2.21
IR_DETECTOR_A: C1.1, R12.2, U1.10, U$31.P$2
IR_DETECTOR_A1: C4.1, R26.2, U2.10, U$63.P$2
IR_DETECTOR_B: C3.1, R14.2, U1.13, U$32.P$2
IR_DETECTOR_B1: C6.1, R28.2, U2.13, U$64.P$2
unnamed: BT1.1, S3.3
unnamed: D1S1.C, D1S2.C, D1S4.C, D1S5.C, D1S6.C, D1S7.C, DIS3.C, Q1.3
unnamed: Q2.1, R10.2
unnamed: Q1.1, R9.2
unnamed: D2S1.C, D2S2.C, D2S3.C, D2S4.C, D2S5.C, D2S6.C, D2S7.C, Q2.3
unnamed: Q3.1, R11.2
unnamed: D3S1.C, D3S2.C, D3S3.C, D3S4.C, D3S5.C, D3S6.C, D3S7.C, Q3.3
unnamed: Q4.1, R23.2
unnamed: D1S3.C, D1S8.C, D1S9.C, D1S10.C, D1S11.C, D1S12.C, DIS1.C, Q4.3
unnamed: D2S8.C, D2S9.C, D2S10.C, D2S11.C, D2S12.C, D2S13.C, D2S14.C, Q5.3
unnamed: D3S8.C, D3S9.C, D3S10.C, D3S11.C, D3S12.C, D3S13.C, D3S14.C, Q6.3
unnamed: D3.A, R15.2
unnamed: D1.A, R1.2
unnamed: Q5.1, R24.2
unnamed: Q6.1, R25.2
unnamed: BT2.1, S6.3
unnamed: J12.2, R1.1, R15.1
unnamed: D1.C, D3.C, J12.1
unnamed: J24.2, R29.1, R30.1
unnamed: D2.C, D4.C, J24.1
unnamed: D4.A, R30.2
unnamed: D2.A, R29.2
SEG1: D1S1.A, D2S1.A, D3S1.A, R2.2
SEG2: D1S2.A, D2S2.A, D3S2.A, R3.2
SEG3: D2S3.A, D3S3.A, DIS3.A, R4.2
SEG4: D1S4.A, D2S4.A, D3S4.A, R5.2
SEG5: D1S5.A, D2S5.A, D3S5.A, R6.2
SEG6: D1S6.A, D2S6.A, D3S6.A, R7.2
SEG7: D1S7.A, D2S7.A, D3S7.A, R8.2
SEG8: D1S10.A, D2S12.A, D3S12.A, R16.2
SEG9: D1S11.A, D2S13.A, D3S13.A, R19.2
SEG10: D1S3.A, D2S8.A, D3S8.A, R17.2
SEG11: D2S9.A, D3S9.A, DIS1.A, R18.2
SEG12: D1S9.A, D2S11.A, D3S11.A, R21.2
SEG13: D1S8.A, D2S10.A, D3S10.A, R20.2
SEG14: D1S12.A, D2S14.A, D3S14.A, R22.2
V_BATT: C2.1, J1.2, R13.2, S3.2, U1.4, U1.18, U$31.P$1, U$32.P$1
V_BATT1: C5.1, J13.2, R27.2, S6.2, U2.4, U2.18, U$63.P$1, U$64.P$1
V_EXT: J9.1, S3.1
V_EXT1: J21.1, S6.1

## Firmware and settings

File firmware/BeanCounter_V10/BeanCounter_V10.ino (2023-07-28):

/************************************************************************************************
 *           --------------------------------------------------------------------------------
 *            ______                     ______                     __              
 *           |   __ \.-----.---.-.-----.|      |.-----.--.--.-----.|  |_.-----.----.
 *          |   __ <|  -__|  _  |     ||   ---||  _  |  |  |     ||   _|  -__|   _|
 *         |______/|_____|___._|__|__||______||_____|_____|__|__||____|_____|__|  
 *                                                       SMT Parts Counting Tool
 *       ( )         ( )         ( )         ( )         ( )         ( )         ( )
 *      --------------------------------------------------------------------------------
 * 
 * Ver 1.0
 * Targeting ATtiny861V-10MU
 * Built in Arduino using Spence Konde's ATTinyCore (https://github.com/SpenceKonde/ATTinyCore)
 * 
 * Copyright 2022 Nick Poole 
 * 
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
 * THE SOFTWARE IS PROVIDED "AS IS", WITHOUT WARRANTY OF ANY KIND, EXPRESS OR IMPLIED, INCLUDING 
 * BUT NOT LIMITED TO THE WARRANTIES OF MERCHANTABILITY, FITNESS FOR A PARTICULAR PURPOSE AND 
 * NONINFRINGEMENT. IN NO EVENT SHALL THE AUTHORS OR COPYRIGHT HOLDERS BE LIABLE FOR ANY CLAIM, 
 * DAMAGES OR OTHER LIABILITY, WHETHER IN AN ACTION OF CONTRACT, TORT OR OTHERWISE, ARISING FROM, 
 * OUT OF OR IN CONNECTION WITH THE SOFTWARE OR THE USE OR OTHER DEALINGS IN THE SOFTWARE.
 ************************************************************************************************/

#include <EEPROM.h>

// Pin defines
#define DIGIT1_CATHODE 8
#define DIGIT2_CATHODE 9
#define DIGIT3_CATHODE 10
#define IRLED 11
#define STARTBTN 12
#define SETBTN 13
#define IRSENSOR_A A9
#define IRSENSOR_B A6

// EEPROM Addresses
#define EEPROM_ADDR_PITCH 0x00
#define EEPROM_ADDR_MODE 0x01

// This is the amount of dead time where we allow a digit
// to be on before moving on to the next. Ideally, we would
// never busy-wait like this. We're already polling the
// IR sensors in the downtime during count mode. This is
// just used to increase subjective display brightness
// in modes where nothing needs to be done between segment
// updates
int scanDelay = 500;

// These variables are used to store the state of the IR
// interruptors between checks, particularly when counting
// in two-sensor up/down mode.
byte state_previous = 0b00;
byte state_a = 0b01;
byte state_b = 0b10;
bool bool_state_previous = 1;

// These bytes are used to store the state of every LED in the
// 7-segment display. They are essentially a frame buffer for the
// 7-seg.
byte digit1 = 0;
byte digit2 = 0;
byte digit3 = 0;

// Device Mode
// This is the state of the device wrt the top-level state machine.
// 0 - IDLE/STOP
// 1 - COUNTING
// 2 - RESET
// 3 - SETTINGS MENU
byte deviceMode = 0;

// Return Mode stores the state number of the mode that a given
// mode "exits" to. This is useful when going to mode 3 because
// we should always return from the Settings Menu into the mode
// that we entered from
byte returnMode;

// Counting Mode
// 0: Inventory Mode
// In Inventory Mode, we use only one IR interruptor. This is
// faster because we only need to read one ADC and the decision-making
// is simpler. Also, because it's direction agnostic, it correctly
// handles end/start of tape.
// 1: Dispense Mode
// In Dispense Mode we use both IR interruptors to create an encoder
// with the carrier tape. This allows us to determine the direction
// of the tape at the expense of counting more slowly. Also, because
// end/start of tape transitions look identical to motion in the
// opposite direction, we can't correctly count end/start of tape.
bool countingMode = 0;

// pitch of the parts on the carrier tape in mm
byte pitch = 4;

// ratio of holes in the carrier tape to actual parts,
// calculated based on the pitch
float ratio = 1.0;

// displayBuf is a place to store a value to be
// displayed on the 7-seg using the translateSegments()
// method
int displayBuf = 0;

// count is a place to store the parts count, especially
// when the display is showing something different
int count = 0;

// numPos is used to store the individual digits of a
// number in order of their decimal place. This is the
// output buffer of the numPositions() method. It's
// global to avoid passing memory pointers around and
// inevitably creating a hard to diagnose bug.
byte numPos[10] = {0, 0, 0, 0, 0, 0, 0, 0, 0, 0};

// This is a lookup table of segment states in order
// their integer value. i.e. segLUT[6] returns the
// LED states to display a '6'
const byte segLUT[10] = {
    0b01110111,
    0b00100100,
    0b01011101,
    0b01011011,
    0b00111010,
    0b01101011,
    0b01101111,
    0b01010010,
    0b01111111,
    0b01111010};

// We don't do much in setup() just set some
// pinModes and initial pin states. We also check
// the EEPROM for saved user settings
void setup()
{

    for (int i = 0; i < 12; i++)
    {
        pinMode(i, OUTPUT);
        digitalWrite(i, 0);
    }

    for (int i = 12; i < 14; i++)
    {
        pinMode(i, INPUT_PULLUP);
    }

    pinMode(IRSENSOR_A, INPUT);
    pinMode(IRSENSOR_B, INPUT);
    loadSettings();
    delay(50);
    selfTest();
    delay(50);
    //digitalWrite(IRLED, 1);
}

// The main loop just manages the state machine
void loop()
{

    switch (deviceMode)
    {
    case 0:
        mode0();
        break;
    case 1:
        mode1();
        break;
    case 2:
        mode2();
        break;
    case 3:
        mode3();
        break;
    default:
        deviceMode = 0;
        break;
    }

  //ADC TEST MODE 
  //translateSegments(analogRead(A9));
  //updateLED();  
  
}

// Check EEPROM for user settings and load them
void loadSettings()
{
    byte nvmPitch, nvmMode;
    EEPROM.get(EEPROM_ADDR_PITCH, nvmPitch);
    EEPROM.get(EEPROM_ADDR_MODE, nvmMode);

    // We're hypervigilant about writing a valid value to pitch,
    // This way even if EEPROM gets corrupted by low battery,
    // At least the pitch ends up in a known and user-correctable
    // state
    if (nvmPitch == 1 || nvmPitch == 2 || nvmPitch == 4 || nvmPitch == 8 || nvmPitch == 12 || nvmPitch == 16)
    {
        pitch = nvmPitch;
        ratio = 4.0 / int(pitch);
    }

    if (nvmMode == 0x00)
    {
        countingMode = 0;
    }
    else if (nvmMode == 0x01)
    {
        countingMode = 1;
    }
    return;
}

// Mode 0: IDLE/STOP
// In this mode, the BeanCounter isn't counting. It just displays the last
// count and ignores the IR interruptors. To save battery, it also shuts off
// the IR illuminators.
void mode0()
{

    if (digitalRead(STARTBTN) == 0)
    {
        deviceMode = 2;
        returnMode = 1;
        return;
    }

    digitalWrite(IRLED, 0);

    byte blinkTimer = 0;

    while (deviceMode == 0)
    {

        blinkTimer++;

        updateLED();

        if (digitalRead(STARTBTN) == 0)
        {
            delay(500);
            deviceMode = 1;
        }

        if (digitalRead(SETBTN) == 0)
        {
            delay(500);
            deviceMode = 3;
            returnMode = 0;
        }

        if(blinkTimer > 125)
        {
            translateSegments(displayBuf);
        }
        else
        {
            digit1 = 0;
        }
    }
}

// Mode 1: COUNTING
// In this mode, we're just checking the user buttons between counting parts
// and updating the display. The actual counting (polling the IR interruptors)
// happens inside of updateLED() for timing reasons.
void mode1()
{

    if (digitalRead(STARTBTN) == 0)
    {
        deviceMode = 2;
        returnMode = 0;
        return;
    }

    digitalWrite(IRLED, 1);

    delay(50);

    while (deviceMode == 1)
    {

        updateLED();

        if (digitalRead(STARTBTN) == 0)
        {
            delay(500);
            deviceMode = 0;
        }

        if (digitalRead(SETBTN) == 0)
        {
            delay(500);
            deviceMode = 3;
            returnMode = 1;
        }

        translateSegments(displayBuf);
    }
}

// Mode 2: RESET
// In this mode, we wait to see if the user really means it
// (if they're holding the button down) and then we reset the
// counter
void mode2()
{
    while (deviceMode == 2)
    {
        for (int i = 0; i < 100; i++)
        {
            updateLED();
        }
        delay(300);
        if (digitalRead(STARTBTN) == 1)
        {
            selfTest();
            count = 0;
            displayBuf = 0;
            deviceMode = returnMode;
        }
    }
}

// Mode 3: SETTINGS MENU
// In mode 3, the SETUP button cycles through various settings that can be
// adjusted using the COUNT/RESET button. In order to exit the mode 3, the
// user must cycle through the entire settings menu. Probably OK because the
// user likely won't adjust the settings often.
void mode3()
{
    byte mode3state = 0;

    while (deviceMode == 3)
    {

        switch(mode3state)
        {
            case 0:
                if (digitalRead(STARTBTN) == 0)
                {
                    delay(200);
                    switch (pitch)
                    {
                    case 1:
                        pitch = 2;
                        break;
                    case 2:
                        pitch = 4;
                        break;
                    case 4:
                        pitch = 8;
                        break;
                    case 8:
                        pitch = 12;
                        break;
                    case 12:
                        pitch = 16;
                        break;
                    case 16:
                        pitch = 1;
                        break;
                    }
                    ratio = 4.0 / int(pitch);
                }
                if (digitalRead(SETBTN) == 0)
                {
                    delay(200);
                    mode3state = 1;
                }
                numPositions(pitch);
                digit3 = segLUT[numPos[0]];
                digit2 = segLUT[numPos[1]];
                digit1 = 0b01111100; // "P" for Pitch
                updateLED();
                break;
            
            case 1:
                if (digitalRead(STARTBTN) == 0)
                {
                    delay(200);
                    switch (countingMode)
                    {
                    case 0:
                        countingMode = 1;
                        count = 0;
                        displayBuf = 0;
                        break;
                    case 1:
                        countingMode = 0;
                        count = 0;
                        displayBuf = 0;
                        break;
                    }
                }
                if (digitalRead(SETBTN) == 0)
                {
                    delay(200);
                    mode3state = 2;
                }
                if(countingMode == 0){
                    digit1 = 0b00100100; // I
                    digit2 = 0b00001110; // n
                    digit3 = 0b00000111; // v
                }else{
                    digit1 = 0b00011111; // d
                    digit2 = 0b00100100; // I
                    digit3 = 0b01101011; // S
                }
                updateLED();
                break;

            case 2:
                // Check EEPROM to see if we've changed the settings
                // and if we have, save the new ones
                byte nvmPitch, nvmMode;
                EEPROM.get(EEPROM_ADDR_PITCH, nvmPitch);
                EEPROM.get(EEPROM_ADDR_MODE, nvmMode);
                if (nvmPitch != pitch)
                {
                    EEPROM.put(EEPROM_ADDR_PITCH, pitch);
                }
                if (nvmMode != countingMode)
                {
                    EEPROM.put(EEPROM_ADDR_MODE, countingMode);
                }                
                deviceMode = returnMode; // Return to whichever mode sent us here
                break;
        }

    }
}

// This method takes the int stored in displayBuf and
// shoves it into numPositions, which results in the int
// being split into digits. Each digit is fetched from the
// result array numPos[], translated into a String of LED
// segment states by segLUT[] and assigned to a
// display digit
void translateSegments(int displayBuf)
{
    numPositions(displayBuf);
    digit3 = segLUT[numPos[0]];
    digit2 = segLUT[numPos[1]];
    digit1 = segLUT[numPos[2]];
}

// This method is called to "scan" the 7-seg once. In order to
// achieve the Persistence of Vision effect necessary to make the
// display visible, this method needs to be called as often as possible.
// In order to keep BOM costs low, we aren't using any external comparators
// which means we need to use the ADCs on the uC. This also means that
// we can't update our counter in an interrupt. The only alternative
// is to poll the IR interruptors as often as possible. Luckily, we
// need to be busy periodically between updating each digit of the
// display, so we use that time to do our counting. If we don't need to
// be coounting, we busywait instead.
void updateLED()
{

    for (int i = 0; i < 7; i++)
    {
        digitalWrite(i, bitRead(digit1, 6-i));
    }

    digitalWrite(DIGIT1_CATHODE, 1);
    if (deviceMode == 1)
    {
        updateCount();
    }
    else
    {
        delayMicroseconds(scanDelay);
    }
    digitalWrite(DIGIT1_CATHODE, 0);

    for (int i = 0; i < 7; i++)
    {
        digitalWrite(i, bitRead(digit2, 6-i));
    }

    digitalWrite(DIGIT2_CATHODE, 1);
    if (deviceMode == 1)
    {
        updateCount();
    }
    else
    {
        delayMicroseconds(scanDelay);
    }
    digitalWrite(DIGIT2_CATHODE, 0);

    for (int i = 0; i < 7; i++)
    {
        digitalWrite(i, bitRead(digit3, 6-i));
    }

    digitalWrite(DIGIT3_CATHODE, 1);
    if (deviceMode == 1)
    {
        updateCount();
    }
    else
    {
        delayMicroseconds(scanDelay);
    }
    digitalWrite(DIGIT3_CATHODE, 0);
}

// This method takes an integer as an argument and returns
// an array of digits organized by decimal place.
void numPositions(int num)
{
    for (int i = 0; i < 10; i++)
    {
        numPos[i] = 0;
    }
    byte pos = 0;
    while (num != 0)
    {
        numPos[pos] = num % 10;
        num = num / 10;
        pos++;
    }
    return;
}

// This is the function that actually deals with the ADCs
// and turns blinking lights into parts counts. There are two
// modes we can use to count:
// Mode 0 is "Inventory Mode"
// In Inventory Mode, we use only one IR interruptor. This is
// faster because we only need to read one ADC and the decision-making
// is simpler. Also, because it's direction agnostic, it correctly
// handles end/start of tape.
// Mode 1 is "Dispense Mode"
// In Dispense Mode we use both IR interruptors to create an encoder
// with the carrier tape. This allows us to determine the direction
// of the tape at the expense of counting more slowly. Also, because
// end/start of tape transitions look identical to motion in the
// opposite direction, we can't correctly count end/start of tape.
void updateCount()
{

    if (countingMode == 1)
    {

        /**************** Dispense Mode ****************/
        // Fetch the ADC
        int adc_a = analogRead(IRSENSOR_A); 
        int adc_b = analogRead(IRSENSOR_B);

        // Here we create a deadzone between high and low 
        // sensor readings to prevent miscounting. Theoretically, 
        // you don't need to do this, but since this device operates 
        // in meatspace, it's possible for sensor values to fluctuate
        // even if the tape isn't moving. Without deadzone, it was 
        // possible to occlude the sensor just enough for it to start 
        // "counting" parts at 1/2 polling speed.
        // The state values may look like nonsense but it's really just 
        // assigning the state of each IR interruptor to a separate bit in 
        // a two bit binary number. This makes state transitions easier to 
        // track
        if (adc_a > 100)
        {
            state_a = 0b01;
        }
        else if (adc_a < 50)
        {
            state_a = 0b00;
        }
        if (adc_b > 100)
        {
            state_b = 0b10;
        }
        else if (adc_b < 50)
        {
            state_b = 0b00;
        }

        byte state_current = state_a + state_b;

        // If the state we just measured is different than the last time we were 
        // polled, it means the tape has moved! Time to count!
        if (state_current != state_previous)
        {
            // The state transitions for tape moving "up" are: 
            // 00 01 11 10
            // and for a tape moving "down" are: 
            // 00 10 11 01
            // but because of the geometry involved, the "00" 
            // state is very short, we shouldn't rely on detecting 
            // it. So we only increment/decrement on the transition 
            // out of "11" which is our longest state.
            if (state_previous == 0b11)
            {
                switch (state_current)
                {
                case 0b01:
                    count++;
                    // We don't keep track of which way we're counting
                    // so instead we just count into the negative and 
                    // display the absolute value
                    displayBuf = abs(count) * ratio; // multiply by hole-to-part ratio
                    break;
                case 0b10:
                    count--;
                    displayBuf = abs(count) * ratio;
                    break;
                }
            }
            state_previous = state_current;
        }

    }
    else
    {
        /**************** Inventory Mode ****************/
        // Fetch the ADC
        int adc_a = analogRead(IRSENSOR_A);

        // Create a bool to store the sensor state
        bool bool_state_current;

        // We need to do the deadzone trick here as well for stability
        if (adc_a > 100)
        {
            bool_state_current = 1;
        }
        else if (adc_a < 50)
        {
            bool_state_current = 0;
        }
        
        // If the state we just measured is different than the last time we were 
        // polled, it means the tape has moved! Time to count!
        if (bool_state_current != bool_state_previous)
        {
            if (bool_state_current == 1)
            {
                count++;
                displayBuf = count * ratio; // multiply by hole-to-part ratio
            }
            bool_state_previous = bool_state_current;
        }
    }
}

void selfTest()
{
  byte pass = 0;
  
  for (byte i = 0; i < 10; i++)
  {
    digitalWrite(IRLED, 1);
    delay(20);
    if ( analogRead(IRSENSOR_A) > 100 && analogRead(IRSENSOR_B) > 100 )
    {
      pass++;
    }
    digitalWrite(IRLED, 0);
    delay(20);
    if ( analogRead(IRSENSOR_A) < 50 && analogRead(IRSENSOR_B) < 50 )
    {
      pass++;
    }
  }

  if (pass < 15)
  {
    digit1 = 0b00101111; // b
    digit2 = 0b01111110; // A
    digit3 = 0b00011010; // t
    for(int i = 0; i < 500; i++){updateLED();}
    digit1 = 0b01101101; // E
    digit2 = 0b00001100; // r
    digit3 = 0b00001100; // r
    for(int i = 0; i < 500; i++){updateLED();}
  }

  digitalWrite(IRLED, 0);

  return;
}

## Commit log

2021-11-06 Initial Commit v0.01
    [Keychain_Tape.GBL, Keychain_Tape.GBO, Keychain_Tape.GBP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]
2021-11-10 cleaning up before giving out the link
    [Keychain_Tape.GBL, Keychain_Tape.GBO, Keychain_Tape.GBP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]
2021-11-26 Pushing PDFs for non EAGLE users to peek at the docs
    Also, firmware from the Twitter demo
    [Keychain_Tape.brd, Keychain_Tape.sch]
2021-11-30 Board and Code changes. Close to v1.0
    Board and Code changes. Close to v1.0
    [0_8mm_Layers.brd, 0_8mm_Layers.sch, 1_6mm_Layer.brd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]
2022-01-22 Doing radical things to unbork on Win machine
    Pardon the mess
    [0_8mm_Layers.brd, 0_8mm_Layers.sch, 1_6mm_Layer.brd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]
2022-01-22 Maybe this fixes things
    [0_8mm_Layers.brd, 0_8mm_Layers.sch, 1_6mm_Layer.brd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]
2022-04-04 Housekeeping
    - Remove prototypes
    - Remove EAGLE backup files
    - Archive GHPages site
    - Commit 3D CAD
    [0_8mm_Layers.brd, 1_6mm_Layer.brd, BC_3DP_Simple_Resin v1.3mf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]
2022-08-05 Cleanup, add support files
    [BeanCounter-Panel.brd, BeanCounter-centroids.csv, BeanCounter_V10.brd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]
2023-07-28 Uploading missing docs
    [BeanCounter-Panel-for-3DM.brd, BeanCounter_Tall_Slot_Mod.stl, BeanCounter_v10_Stock.f3d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]
2023-11-09 Add programming batch file
    [BeanCounter_Rev11.step, BeanCounter_Rev11.stl]

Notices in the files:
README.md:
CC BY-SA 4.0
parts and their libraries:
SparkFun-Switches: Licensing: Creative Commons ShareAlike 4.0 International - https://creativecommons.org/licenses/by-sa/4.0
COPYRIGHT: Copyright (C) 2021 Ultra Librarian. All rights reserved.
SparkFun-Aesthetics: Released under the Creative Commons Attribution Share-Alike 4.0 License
